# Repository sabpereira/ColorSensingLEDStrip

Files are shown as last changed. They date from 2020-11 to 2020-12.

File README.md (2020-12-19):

# Color Sensing LED Strip

This repository conatins the documentation and relevant files for the Color Sensing LED Strip controller, a controller that allows for the user to scan a desired color to set an LED strip to the color, as well as allowing other methods of user input. 

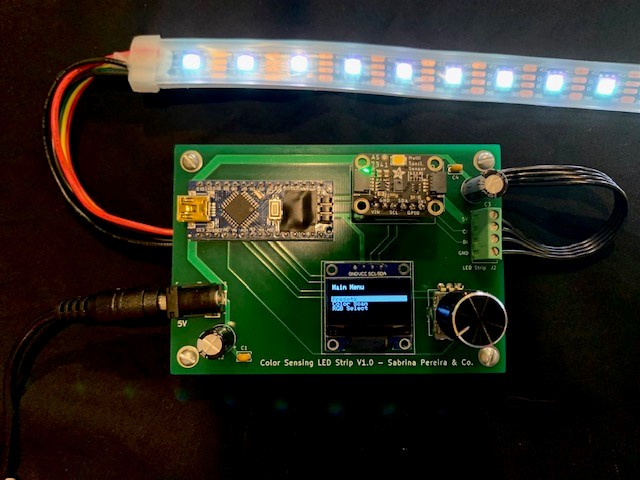
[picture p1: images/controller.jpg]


## Overview
The Color Sensing LED Strip controller enables the user to set the color of an LED strip by choosing to scan a light source of a desired color to replicate (such as from a phone), select the desired RGB values, or choose from a preset selection of colors, including the last color scanned. Please review the video below or [click here]( https://youtu.be/J2j3cKCgywg) for a demo of the controller in action.

Color Sensing LED Strip Demo (http://www.youtube.com/watch?v=J2j3cKCgywg "Color Sensing LED Strip Demo")

The user interface displays text and menus OLED ".96 display, with selections made through the use of a rotary encoder. The color spectrometer Adafruit AS7341 is used to scan the desired color. Adafruit DotStars are used for the LEDs.

## User Interface 

The Color Sensing LED Strip experiments with various methods of user input with only a rotary encoder and a button as input. The original concept for the user interface can be viewed and interacted with in `User Experience.pptx`. The actual implemented UI is a simplified version of the original concept. The PCB layout was also designed with the user experience in mind, as will be explained in the relevant section.

## Hardware

The relevant Kicad files and bill of materials can be found in the `hardware/` folder of this repository.

### Schematic 

The folowing schematic each of the components used in the controller and how they connect. The Arduino Nano communicates with the color spectrometer and LCD screen via I2C. 

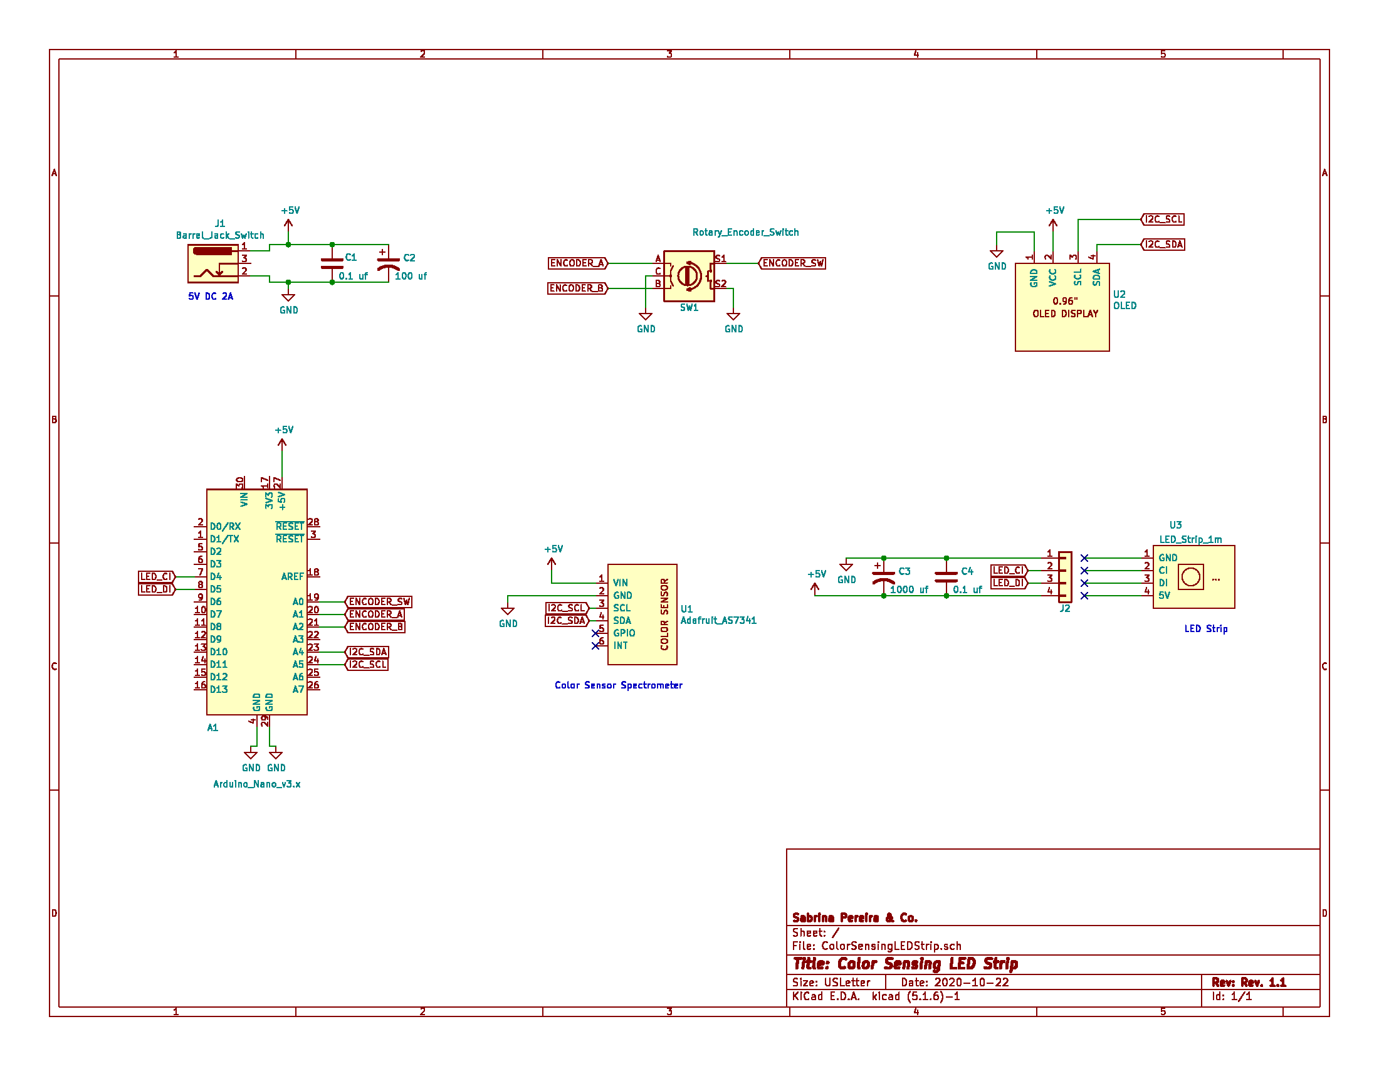
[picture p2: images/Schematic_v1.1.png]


### PCB Layout

The PCB layout was planned out for user convenience. The power supply is connected on the left, with the LEDs connected on the right for ease of setup wherever the LEDs are intented to be placed. The LCD screen and rotary encoder are placed towards the bottom of the board for easy access by the user, while the color spectrometer is placed high on the board such that the LCD screen is still visible while the scan is taking place.

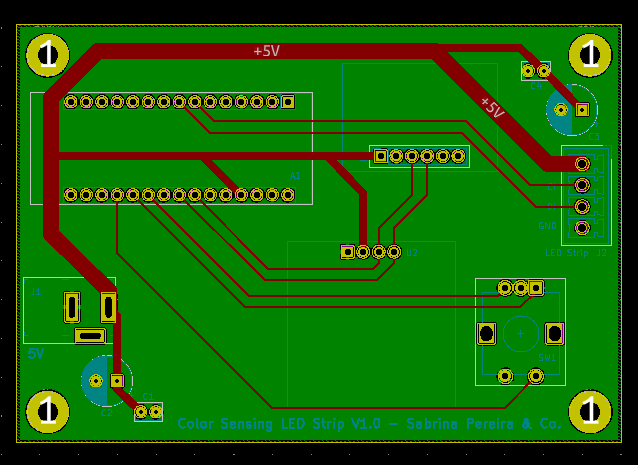
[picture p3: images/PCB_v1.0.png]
 

## Software 

Source code can be found in the `src/` folder of this repository.

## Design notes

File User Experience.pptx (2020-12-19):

## Main Menu HEX: #FFFFFF Mode: Blinking

Scan Color

Set Color

Set Mode

## Scan Color

Start Scan

Cancel

## Color Scan Complete Color Captured: HEX #XXXXXX

Color OK

Rescan

LEDs change color as soon as scan is complete (sets variable for color to show)

## Save Color in Slot? Color: HEX #XXXXXX

No

Yes

## Save Slots Saving : HEX: #XXXXXX

Slot 1: #XXXXXX

Slot 2: #FFFFFF

Slot 3: #FFFFFF

Slot 4: #FFFFFF

Slot 5: #FFFFFF

Slot 6: #FFFFFF

## Color Saved

OK

## Set Color

Start Set Color

Currently only setting RGB

Cancel

## Set Red : 0-255

<- 200 ->

OK

LEDs change color changes as user turns the knob. Current values displayed initially

## Set Green: 0-255

<- 200 ->

OK

LEDs change color changes as user turns the knob. Current values displayed initially

## Set Blue: 0-255

<- 200 ->

OK

LEDs change color changes as user turns the knob. Current values displayed initially

## Color Set Complete Color Set: HEX #XXXXXX

Color OK

Re-set

## Set Mode

All On

Blinking

Gradient

X

LEDs change pattern as user turns the knob. As soon as this setting is brought on switched to all on

X

X

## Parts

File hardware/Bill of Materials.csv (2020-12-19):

Qty | Value | Vendor | Price
1 | Arduino_Nano_v3.x | Amazon | 13.99
1 | Barrel_Jack_Switch | DK: CP-202A-ND | 0.6
1 | 4-Wire Screw Terminal | DK: 277-5744-ND | 2.58
2 | 10k | DK: CF18JT10K0 | 0.1
1 | Rotary_Encoder_Switch | Amazon | 7.99
1 | Adafruit_AS7341 | Adafruit: 4698, DK: 1528-4698-ND | 15.95
1 | OLED | Amazon | 11.99
1 | LED_Strip_1m | Adafruit: 2239 | 29.95
2 | 0.1 uf | DK: BC1084TR-ND | 0.23
1 | 100 uf | DK: 493-10478-1-ND | 0.49
1 | 1000 uf | DK: 1189-4233-1-ND | 0.52
1 | JST SM 4 Wire connectors | Adafruit: 578 | 1.5
1 | Barrel Power Supply | Amazon | 12.99
1 | 6-Pin Socket | DK: PPPC061LFBN-RC | 0.53

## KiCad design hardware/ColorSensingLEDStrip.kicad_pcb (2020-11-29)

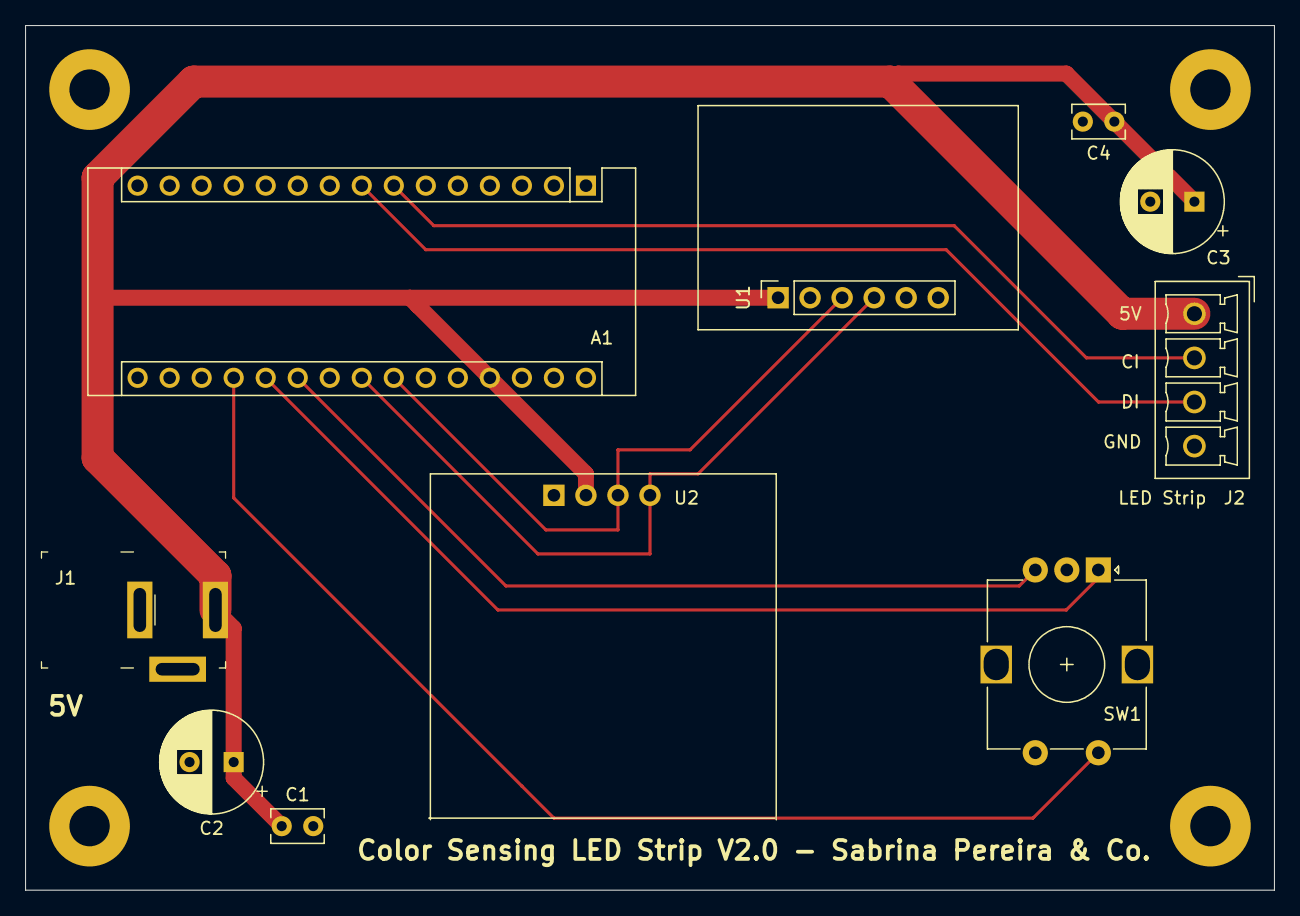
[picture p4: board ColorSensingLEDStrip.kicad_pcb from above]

Board: 2 copper layers, 99.1 x 68.6 mm, 10 parts (0 on the bottom side), 9 nets.

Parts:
A1: Arduino_Nano_v3.x; Arduino_Nano
C1, C4: 0.1 uf; C_Rect_L4.0mm_W2.5mm_P2.50mm
C2: 100 uf; CP_Radial_D8.0mm_P3.50mm
C3: 1000 uf; CP_Radial_D8.0mm_P3.50mm
J1: Barrel_Jack_Switch; Barrel_Jack_5.5mmODx2.1mmID_PJ-202A
J2: 4-Wire Screw Terminal; PhoenixContact_MCV_1,5_4-G-3.5_1x04_P3.50mm_Vertical
SW1: Rotary_Encoder_Switch; RotaryEncoder_Alps_EC12E-Switch_Vertical_H20mm
U1: Adafruit_AS7341; Adafruit_AS7341_PinSocket
U2: OLED; OLED_0.96

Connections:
+5V: A1.27, C1.1, C2.1, C3.1, C4.1, J1.1, J2.1, U1.1, U2.2
ENCODER_A: A1.20, SW1.A
ENCODER_B: A1.21, SW1.B
ENCODER_SW: A1.19, SW1.S1
GND: A1.4, A1.29, C1.2, C2.2, C3.2, C4.2, J1.2, J2.4, SW1.C, SW1.S2, U1.2, U2.1
I2C_SCL: A1.24, U1.3, U2.3
I2C_SDA: A1.23, U1.4, U2.4
LED_CI: A1.7, J2.2
LED_DI: A1.8, J2.3

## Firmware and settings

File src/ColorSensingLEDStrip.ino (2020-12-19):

/////////////////////////////////////////
//
//       Color Sensing LED Strip 
//
//       Sabrina Pereira 2020
//
/////////////////////////////////////////

#include <SPI.h>
#include <Wire.h>
#include <EEPROM.h>
#include <Adafruit_GFX.h>
#include <Adafruit_SSD1306.h>

#define SCREEN_WIDTH 128 // OLED display width, in pixels
#define SCREEN_HEIGHT 64 // OLED display height, in pixels

// Declaration for an SSD1306 display connected to I2C (SDA, SCL pins)
#define OLED_RESET     -1 // Reset pin # (or -1 if sharing Arduino reset pin)
Adafruit_SSD1306 display(SCREEN_WIDTH, SCREEN_HEIGHT, &Wire, OLED_RESET);

#include <SimpleRotary.h>
// Pin A, Pin B, Button Pin
SimpleRotary rotary(16,15,14);

#include <Adafruit_DotStar.h>
#define NUMPIXELS 20 // Number of LEDs in strip
#define DATAPIN    5
#define CLOCKPIN   4
Adafruit_DotStar strip(NUMPIXELS, DATAPIN, CLOCKPIN, DOTSTAR_BGR);

#include <Adafruit_AS7341.h>
Adafruit_AS7341 as7341;
uint16_t readings[12];


// LED Color components
volatile uint8_t red_component = 0;  
volatile uint8_t green_component = 0;  
volatile uint8_t blue_component = 0;  
uint32_t color = strip.Color(red_component, green_component, blue_component);

// Menu States 
enum State_enum {MAIN, PRESETS, RED_SELECT, GREEN_SELECT, BLUE_SELECT};
uint8_t state = MAIN;
uint8_t prev_state = MAIN;

// Cursor Position for menus
int8_t pos = 0;

// Saved Strings for menus
const char *mainMenuStrings[] = {"Presets", "Color Scan", "RGB Select"};
const char *presetStrings[] = {"Magenta", "Yellow", "Last Color Scan"};

// Variables for rotary encoder readings
uint8_t i; // Turned
uint8_t j; // Pushed



/////////////////////////////////////////
//
//       Setup
//
/////////////////////////////////////////

void setup() {  
  Serial.begin(115200);

  // Wait for communication with the host computer serial monitor
  while (!Serial) {
    delay(1);
  }
  
  if (!as7341.begin()){
    Serial.println("Could not find AS7341");
    while (1) { delay(10); }
  }

  as7341.setATIME(100);
  as7341.setASTEP(999);
  as7341.setGain(AS7341_GAIN_256X);
  as7341.startReading();

  // SSD1306_SWITCHCAPVCC = generate display voltage from 3.3V internally
  if(!display.begin(SSD1306_SWITCHCAPVCC, 0x3C)) { // Address 0x3D for 128x64
    Serial.println(F("SSD1306 failed"));
    for(;;); // Don't proceed, loop forever
  }

  // Set the trigger to be either a HIGH or LOW pin (Default: HIGH)
  // Note this sets all three pins to use the same state.
  rotary.setTrigger(HIGH);

  // Set the debounce delay in ms  (Default: 2)
  rotary.setDebounceDelay(5);

  // Set the error correction delay in ms  (Default: 200)
  rotary.setErrorDelay(50);

  display.display();
  delay(2000); // Pause for 2 seconds

  // Clear the buffer
  display.clearDisplay();
  display.setTextSize(1);      // Normal 1:1 pixel scale
  display.setTextColor(SSD1306_WHITE); // Draw white text
  display.setCursor(1, 0);     // Start at top-left corner
  display.cp437(true);         // Use full 256 char 'Code Page 437' font
  update_main_menu_view(0);

  strip.begin();
  strip.setBrightness(50);
  strip.show(); // Initialize all pixels to 'off'

}


/////////////////////////////////////////
//
//       Main Loop / State Machine
//
/////////////////////////////////////////


void loop() {

  i = rotary.rotate();
  j = rotary.push();
  
  // If CW
  if ( i == 1 ) {
    pos++;
  }

  // If CCW
  if ( i == 2) {
    pos--;
  }

  // If State changes, update correct screen
  if (state != prev_state) {
    pos = 0;

    if (state == MAIN) {
      update_main_menu_view(pos);
    }

    if (state == PRESETS) {
      update_presets_view(pos);
    }

    if (state == RED_SELECT) {
      update_red_select_view(pos);
    }    
    if (state == GREEN_SELECT) {
      update_green_select_view(pos);
    }  
    if (state == BLUE_SELECT) {
      update_blue_select_view(pos);
    }
    prev_state = state;
  }

  // Call State Machine to decide next State
  state_machine_UI(); 
  delay(10);
}



void state_machine_UI(){
// Call the Corresponding State Selecting Functions

switch (state) {     
    case (MAIN):
    {      
      state = main_menu_selection();
      break;
    }
    
    case (PRESETS):
    {      
      state = presets_selection();      
      break;
    }
    
    case (RED_SELECT):
    {      
      state = red_select_selection();      
      break;
    }
    case (GREEN_SELECT): 
    {
      state = green_select_selection();      
      break;
    }
    case (BLUE_SELECT):  
    {
      state = blue_select_selection();      
      break;
    }
  }  
}


/////////////////////////////////////////
//
//       State Selecting Functions
//
/////////////////////////////////////////


uint8_t main_menu_selection() { 

  uint8_t main_menu_len = 2;
  if (pos > main_menu_len) {
  pos = 0;
  }
  else if (pos <= -1) {
  pos = main_menu_len;
  }

  if ( i == 1 || i == 2 || state != prev_state) {
    update_main_menu_view(pos);
//    Serial.println(pos);
  }

  if ( j == 1 ) {
    switch (pos) {
      case (0)://magenta
        return PRESETS;
        break;
      case (1)://Color scan
        Color_scan();
        return MAIN;
        break;
      case (2)://Manual Input
        return RED_SELECT;
        break;
    }
  }  
  return MAIN;
}


uint8_t presets_selection() { 

  uint8_t menu_len = 2;
  if (pos > menu_len) {
  pos = 0;
  }
  else if (pos <= -1) {
  pos = menu_len;
  }

  if ( i == 1 || i == 2 || state != prev_state) {
    update_presets_view(pos);
//    Serial.println(pos);
  }

  if ( j == 1 ) {
    delay(200);
    switch (pos) {
      case (0)://magenta
        Magenta();
        return MAIN;
        break;
      case (1)://yellow
        Yellow();
        return MAIN;
        break;
      case (2)://Color scan
        GetColor();
        return MAIN;
        break;
    }
  }  
  return PRESETS ;
}

uint8_t red_select_selection() {
      if ( i == 1 || i == 2 || state != prev_state) {
        if ( i == 1 ) {
          red_component++;
        }
          
        // If CCW
        if ( i == 2) {
          red_component--;
        }
        
        update_red_select_view(pos);
        Serial.println(pos);
      }

      if ( j == 1) {
        return GREEN_SELECT;
        Serial.println(state);
      } 

      return RED_SELECT;

}

uint8_t green_select_selection() {
      if ( i == 1 || i == 2 || state != prev_state) {
        if ( i == 1 ) {
          green_component++;
        }
          
        // If CCW
        if ( i == 2) {
          green_component--;
        }
        
        update_green_select_view(pos);
        Serial.println(pos);
      }

      if ( j == 1) {
        return BLUE_SELECT;
      } 

      return GREEN_SELECT;

}


uint8_t blue_select_selection() {
      if ( i == 1 || i == 2 || state != prev_state) {
        if ( i == 1 ) {
          blue_component++;
        }
          
        // If CCW
        if ( i == 2) {
          blue_component--;
        }
        
        update_blue_select_view(pos);
        Serial.println(pos);
      }

      if ( j == 1) {
        color = strip.Color(red_component, green_component, blue_component);
        strip.fill(color);
        strip.show();  
        
        return MAIN;
      } 

      return BLUE_SELECT;

}


/////////////////////////////////////////
//
//       View Updating Functions
//
/////////////////////////////////////////

   
void update_main_menu_view(long pos) {  
  Serial.println("update mm");
  display.clearDisplay();

  display.setCursor(2, 2);
  display.println("Main Menu");
  
  for (int i = 0; i < 3; i++) {
    display.setCursor(2, (22 + 8*i));
    display.println(mainMenuStrings[i]);
  }
  
  display.fillRect(0, pos * 8 + 21, 128, 9, SSD1306_INVERSE);
  display.display();
}

void update_presets_view(long pos) {  
//  Serial.println("update mm");
  display.clearDisplay();

  display.setCursor(2, 2);
  display.println("Presets");
  
  for (int i = 0; i < 3; i++) {
    display.setCursor(2, (22 + 8*i));
    display.println(presetStrings[i]);
  }
  
  display.fillRect(0, pos * 8 + 21, 128, 9, SSD1306_INVERSE);
  display.display();
}


void update_red_select_view(long pos) {  
  Serial.println("R");
  display.clearDisplay();
  display.setCursor(2, 2);
  display.println("R Select");
  display.setCursor(SCREEN_WIDTH/2 -1, SCREEN_HEIGHT/2-5);
  display.println(red_component);
  display.setCursor(2, SCREEN_HEIGHT-12);
  display.println("->");
  display.fillRect(0, SCREEN_HEIGHT-12 - 1, 128, 9, SSD1306_INVERSE);
  display.display();
}

void update_green_select_view(long pos) {  
  Serial.println("G");
  display.clearDisplay();
  display.setCursor(2, 2);
  display.println("G Select");
  display.setCursor(SCREEN_WIDTH/2 -1, SCREEN_HEIGHT/2-5);
  display.println(green_component);
  display.setCursor(2, SCREEN_HEIGHT-12);
  display.println("->");
  display.fillRect(0, SCREEN_HEIGHT-12 - 1, 128, 9, SSD1306_INVERSE);
  display.display();
}

void update_blue_select_view(long pos) {  
  Serial.println("B");
  display.clearDisplay();
  display.setCursor(2, 2);
  display.println("B Select");
  display.setCursor(SCREEN_WIDTH/2 -1, SCREEN_HEIGHT/2-5);
  display.println(blue_component);
  display.setCursor(2, SCREEN_HEIGHT-12);
  display.println("->");
  display.fillRect(0, SCREEN_HEIGHT-12 - 1, 128, 9, SSD1306_INVERSE);
  display.display();
}


/////////////////////////////////////////
//
//       LED Color Changing Functions
//
/////////////////////////////////////////

void Magenta() {
  red_component = 255;
  green_component = 0;
  blue_component = 255;
    
  color = strip.Color(red_component, green_component, blue_component);
  strip.fill(color);
  strip.show();    
}

void Yellow() {
  red_component = 255;
  green_component = 255;
  blue_component = 0;
    
  color = strip.Color(red_component, green_component, blue_component);
  strip.fill(color);
  strip.show();   
}

void GetColor() {
  red_component = EEPROM.read(0);
  green_component = EEPROM.read(1);
  blue_component = EEPROM.read(2);

  color = strip.Color(red_component, green_component, blue_component);
  strip.fill(color);
  strip.show(); 
}



void Color_scan(){

  if (!as7341.readAllChannels()){
    Serial.println("Error AS7341 Reading");
    return;
  }

  as7341.setLEDCurrent(10); // 4mA
  as7341.enableLED(true);
  delay(500);
  
  as7341.getAllChannels(readings);  
  delay(500);


  as7341.enableLED(false);

    red_component = 3*map(readings[9],0,65535, 0, 255);
    green_component = map(readings[3],0,65535, 0, 255);
    blue_component = map(readings[1],0,65535, 0, 255);

    Serial.println(red_component);   
    EEPROM.write(0, red_component); 
    Serial.println(green_component);
    EEPROM.write(1, green_component); 
    Serial.println(blue_component);
    EEPROM.write(2, blue_component); 


    
    color = strip.Color(red_component, green_component, blue_component);
    strip.fill(color);
    strip.show();   
  
}

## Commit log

2020-11-24 Initial commit of project files
    [ColorSensingLEDStrip-B_Cu.gbr, ColorSensingLEDStrip-B_Mask.gbr, ColorSensingLEDStrip-B_SilkS.gbr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]
2020-11-29 v2.0 PCB files
    [ColorSensingLEDStrip-B_Cu.gbr, ColorSensingLEDStrip-B_Mask.gbr, ColorSensingLEDStrip-B_SilkS.gbr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]
2020-12-19 Folder cleaning
    [ColorSensingLEDStrip-B_Cu.gbr, ColorSensingLEDStrip-B_Mask.gbr, ColorSensingLEDStrip-B_SilkS.gbr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]
2020-12-19 Create Bill of Materials.csv
    [Bill of Materials.csv]
